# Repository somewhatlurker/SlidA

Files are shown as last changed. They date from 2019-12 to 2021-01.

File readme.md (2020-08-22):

## SlidA

Code based on [Thinithm](https://github.com/somewhatlurker/thinithm) for Diva Arcade FT only sliders.

* Code quality is non-existent
* Only has minimal testing

Hardware is based on ATmega32u4 Arduinos -- (Pro) Micro or Leonardo. (may work on other boards, but I don't know)  
Also requires 3\*MPR121 and (optionally) 32\*WS2812 compatible LEDs (60/meter premade strip should work well).  
Button input is handled through keyboard buttons, but using an separate button encoder is recommended.

Cheap generic MPR121 modules can be used off a <3.3V supply only, so I suggest to pair them with a 3.3V Pro Micro.  
Adafruit MPR121 modules work off 5V and can be used with any compatible board.

Make sure you set the address of your second and third MPR121s:  
1. (For generic modules only) Cut between the ADD pads on the rear side.
2. Solder a jumper from ADD to 3V for the second MPR121, and SDA for the third.

Requires [QuickMpr121](https://github.com/somewhatlurker/QuickMpr121) and FastLED.

Set pins in pins.h or use the defaults (based around Pro Micro):  
| Function | Pin |
| --- | --- |
| MPR121 SDA | SDA |
| MPR121 SCL | SCL |
| MPR121 IRQ | 4 |
| Keyboard W | 5 |
| Keyboard A | 6 |
| Keyboard S | 7 |
| Keyboard D | 8 |
|Keyboard Return | 9 |
|Slider LED Data | 10 |

Slider sensors should be 32 conductive rectangles (eg. copper tape or PCB fills) against the rear side of ~3mm acrylic.  
They are connected sequentially to the MPR121s from left to right.

Buttons connect between the matching pin and ground.

If you have trouble, try limiting the game FPS to <120.

For now, MIT license (subject to change for future versions)

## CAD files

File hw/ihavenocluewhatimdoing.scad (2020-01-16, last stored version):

pcb_width_main = 97;
pcb_width_ledsoffset = 3;
pcb_width_total = pcb_width_main + pcb_width_ledsoffset;
pcb_height_main = 85.7;
pcb_height_leds = 8.1;
pcb_height_total = pcb_height_main + pcb_height_leds;

pcb_hole_dist_x = 6.175;
pcb_hole_dist_y = 3.175;
pcb_hole_size = 3.1;

top_thickness = 2;
key_thickness = 3;
pcb_thickness = 1.6;
space_thickness = 8;
bottom_thickness = 2;
wall_thickness = 2;

wall_height = key_thickness + pcb_thickness + space_thickness;
full_height = top_thickness + wall_height + bottom_thickness;

slider_height = 136;
top_width = 530;
bottom_width = 530;
slider_y_adjust = -9.5;

slider_bevel_x = 44;
slider_bevel_y = 28;

key_separator_width = 3;
key_top_bottom_padding = top_thickness;
key_area_width = pcb_width_main * 4 + key_separator_width;
key_area_height = pcb_height_total - pcb_hole_dist_y*2 - pcb_hole_size - key_top_bottom_padding*2 - .25;

tab_tolerance = 0.05;

hole_resolution = 50;

corner_rounding = 2;


module slider_holes (n = 4)
{
    for (i=[0:n-1])
    {
        translate ([(-pcb_width_main/2) * n + pcb_width_main * i, -pcb_height_total/2, 0])
        {
            translate ([pcb_hole_dist_x, pcb_hole_dist_y, 0])
            {
                circle(pcb_hole_size/2, $fn=hole_resolution);
            }
            translate ([pcb_width_main - pcb_hole_dist_x, pcb_hole_dist_y, 0])
            {
                circle(pcb_hole_size/2, $fn=hole_resolution);
            }
            translate ([pcb_hole_dist_x, pcb_height_total - pcb_hole_dist_y, 0])
            {
                circle(pcb_hole_size/2, $fn=hole_resolution);
            }
            translate ([pcb_width_main - pcb_hole_dist_x, pcb_height_total - pcb_hole_dist_y, 0])
            {
                circle(pcb_hole_size/2, $fn=hole_resolution);
            }
        }
    }
    
    translate ([-key_area_width/2 - pcb_hole_size/2 - .15, 0, 0])
    {
        circle(pcb_hole_size/2, $fn=hole_resolution);
    }
    translate ([key_area_width/2 + pcb_hole_size/2 + .15, 0, 0])
    {
        circle(pcb_hole_size/2, $fn=hole_resolution);
    }
}

module slider_pcbs (n = 4)
{
    corner_rad = 1.27;
    
    color("white", 1.0)
    linear_extrude (height = pcb_thickness)
    difference ()
    {
        for (i=[0:n-1])
        {
            translate ([(-pcb_width_main/2) * n + pcb_width_main * i, -pcb_height_total/2])
            {
                union ()
                {
                    // main body full width (not full height)
                    translate ([0, pcb_height_leds])
                    {
                        square([pcb_width_main, pcb_height_main - corner_rad]);
                    }
                    // main body full height (not full width)
                    translate ([corner_rad, pcb_height_leds])
                    {
                        square([pcb_width_main - corner_rad * 2, pcb_height_main]);
                    }
    
                    // main body corners
                    translate ([corner_rad, pcb_height_total - corner_rad])
                    {
                        circle(r = corner_rad, $fn=hole_resolution);
                    }
                    translate ([pcb_width_main - corner_rad, pcb_height_total - corner_rad])
                    {
                        circle(r = corner_rad, $fn=hole_resolution);
                    }
                    
                    // led section full width (not full height)
                    translate ([pcb_width_ledsoffset, corner_rad])
                    {
                        square([pcb_width_main, pcb_height_leds - corner_rad]);
                    }
                    // led section full height (not full width)
                    translate ([pcb_width_ledsoffset + corner_rad, 0])
                    {
                        square([pcb_width_main - corner_rad * 2, pcb_height_leds]);
                    }
                    
                    // led section corners
                    translate ([pcb_width_ledsoffset + corner_rad, corner_rad])
                    {
                        circle(r = corner_rad, $fn=hole_resolution);
                    }
                    translate ([pcb_width_ledsoffset + pcb_width_main - corner_rad, corner_rad])
                    {
                        circle(r = corner_rad, $fn=hole_resolution);
                    }
                }
            }
        }
        slider_holes(n);
    }
}

module slider_keys (width = key_area_width, height = key_area_height, thickness = key_thickness, top_gap = 0, top_border = key_top_bottom_padding, bottom_border = key_top_bottom_padding + pcb_hole_size + 1.5, top_border_retainer = key_top_bottom_padding)
{
    key_count = 16;
    sep_width = key_separator_width;
    key_width = ((width - (key_count + 1) * key_separator_width) / key_count);
    key_height = height;
    
    
    // keys
    color("blue", 1.0)
    linear_extrude (height = thickness)
    for (i=[0:key_count-1])
    {
        translate ([-width/2 + (sep_width + key_width) * i + sep_width + 0.075, -key_height/2])
        {
            square([key_width - 0.15, key_height - 0.1]);
        }
    }
    
    // separators + frame
    color("green", 1.0)
    linear_extrude (height = thickness)
    difference ()
    {
        union ()
        {
            // separators + frame
            for (i=[0:(key_count)/4 - 1])
            {
                for (j=[0:3])
                {
                    translate ([-width/2 + (sep_width + key_width) * (i*4 + j), -key_height/2])
                    {
                        square([sep_width, key_height]);
                    }
                }
                
                // bottom strip
                translate ([-width/2 + (sep_width + key_width) * i*4, key_height/2])
                {
                    difference ()
                    {
                        square([sep_width*4.5 + key_width*4 - pcb_hole_dist_x + pcb_hole_size/2 + 2, bottom_border]);
                        
                        // cutouts to help control light leakage
                        for (j=[0:3])
                        {
                            translate ([-0.3 + (sep_width + key_width) * j, 0])
                            {
                                square([0.3, bottom_border - 3]);
                            }
                            translate ([sep_width + (sep_width + key_width) * j, 0])
                            {
                                square([0.3, bottom_border - 3]);
                            }
                        }
                    }
                }
            }
            // messy hack to add last separator
            translate ([width/2 - sep_width, -key_height/2])
            {
                square([sep_width, key_height]);
            }
            translate ([width/2 - sep_width/2 - pcb_hole_dist_x + pcb_hole_size/2, key_height/2])
            {
                difference ()
                {
                    square([sep_width/2 + pcb_hole_dist_x - pcb_hole_size/2, bottom_border]);
                    
                    translate ([-0.3 + pcb_hole_dist_x - pcb_hole_size/2 - sep_width/2, 0])
                    {
                        square([0.3, bottom_border - 3]);
                    }
                }
            }
            
            // messy hack for top retainer's retention
            translate ([-width/2, -key_height/2 - top_border_retainer])
            {
                square([sep_width, bottom_border]);
            }
            translate ([width/2 - sep_width, -key_height/2 - top_border_retainer])
            {
                square([sep_width, bottom_border]);
            }
        }
        
        slider_holes(4);
    }
    
    
    // top retainer
    color("red", 1.0)
    linear_extrude (height = thickness)
    {
        translate ([-width/2 + sep_width + 0.1, -key_height/2 - top_border])
        {
            square([(key_width + sep_width) * 4 - 0.1, top_border]);
        }
        translate ([-width/2 + sep_width + (key_width + sep_width) * 4 + 0.1, -key_height/2 - top_border])
        {
            square([(key_width + sep_width) * 4 - 0.1, top_border]);
        }
        translate ([-width/2 + sep_width + (key_width + sep_width) * 8 + 0.1, -key_height/2 - top_border])
        {
            square([(key_width + sep_width) * 4 - 0.1, top_border]);
        }
        translate ([-width/2 + sep_width + (key_width + sep_width) * 12 + 0.1, -key_height/2 - top_border])
        {
            square([(key_width + sep_width) * 4 - sep_width - 0.2, top_border]);
        }
    }
}
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

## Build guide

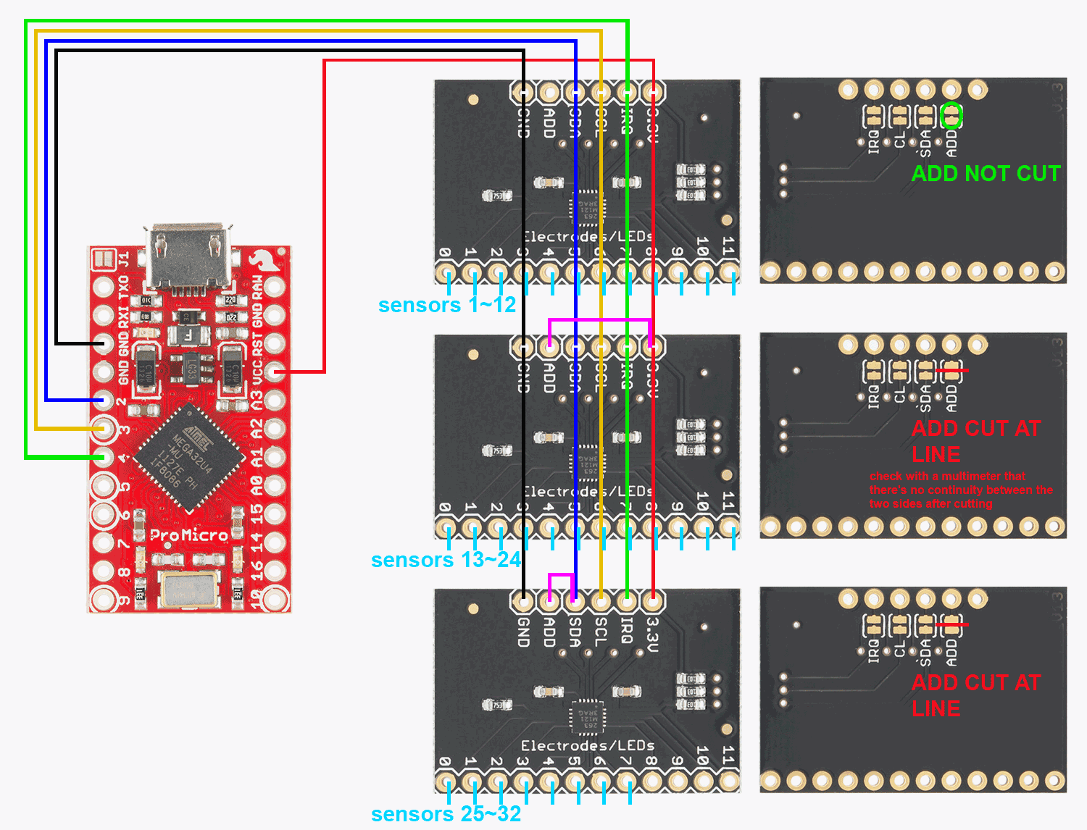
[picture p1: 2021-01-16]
mpr121 wiring.png

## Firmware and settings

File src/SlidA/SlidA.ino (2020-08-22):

#include "segaSlider.h"
#include "sliderdefs.h"
#include "pins.h"
#include <QuickMpr121.h>

#if SLIDER_LEDS
  #include <FastLED.h>
#endif

#if BUTTON_INPUT
  #include <Keyboard.h>
#endif


// disable input scanning and generate fake slider data instead
// (useful for testing protocol without full hardware)
#define FAKE_DATA false

#define FAKE_DATA_TYPE_CHASE 0
#define FAKE_DATA_TYPE_PULSE 1
#define FAKE_DATA_TYPE_TIMERS 2
#define FAKE_DATA_TYPE FAKE_DATA_TYPE_TIMERS

// force enable scanning even with fake data enabled
#define FAKE_DATA_DO_SCANNING true


#if FAKE_DATA && FAKE_DATA_TYPE == FAKE_DATA_TYPE_TIMERS
  #include "debugTimer.h"
  debugTimer loopTimer;
  debugTimer sendTimer;
#endif


#if SLIDER_LEDS
  // slider LED vars
  #define NUM_SLIDER_LEDS 32
  CRGB sliderLeds[NUM_SLIDER_LEDS];
  
  #define RGB_BRIGHTNESS 127
  // 450mA should be unnoticeable up to ~140 brightness, and even then going brighter won't be too bad
  #define RGB_POWER_LIMIT 450
  
  #define MODE_LED_RGB_INDEX NUM_SLIDER_LEDS-1
#endif // SLIDER_LEDS


// status/error LED state
enum errorState : byte {
  ERRORSTATE_NONE = 0, // no error, used for resetting state
  ERRORSTATE_SERIAL_TIMEOUT = 1, // not receiving serial data (timeout)
  ERRORSTATE_PACKET_CHECKSUM = 2, // at least one invalid packet (due to checksum error) was received
  ERRORSTATE_PACKET_OK = 4, // at least one valid packet was received
  ERRORSTATE_PACKET_MAX_REACHED = 8, // number of packets exceeded MAX_PACKETS_PER_LOOP
  ERRORSTATE_SERIAL_SEND_FAILURE = 16, // sendPacket returned false
  ERRORSTATE_MPR_STOPPED = 32, // an mpr121 stopped running
};
errorState operator |(errorState a, errorState b)
{
    return static_cast<errorState>(static_cast<byte>(a) | static_cast<byte>(b));
}
errorState operator |=(errorState &a, errorState b)
{
    return a = (a | b);
}

errorState curError;


// status/error LED pins
#ifdef LED_BUILTIN_RX
  #define STATUS_LED_BASIC_1_PIN LED_BUILTIN_RX // pro micro has no LED_BUILTIN, so use the RX led
  #define STATUS_LED_BASIC_1_USES_RXTX 1
#else
  #define STATUS_LED_BASIC_1_PIN LED_BUILTIN
#endif

#ifdef LED_BUILTIN_TX
  #define STATUS_LED_BASIC_2_PIN LED_BUILTIN_TX // pro micro has no LED_BUILTIN, so use the TX led
  #define STATUS_LED_BASIC_2_USES_RXTX 1
#else
  #define STATUS_LED_BASIC_2_PIN LED_BUILTIN
#endif

#define STATUS_LED_BASIC_1_ERRORS (ERRORSTATE_SERIAL_TIMEOUT | ERRORSTATE_PACKET_CHECKSUM | /*ERRORSTATE_PACKET_MAX_REACHED |*/ ERRORSTATE_SERIAL_SEND_FAILURE | ERRORSTATE_MPR_STOPPED)
#define STATUS_LED_BASIC_2_ERRORS (ERRORSTATE_PACKET_OK)


// slider serial protocol implementation
segaSlider sliderProtocol = segaSlider(&Serial);


// slider protocol packets for reuse
byte sliderBuf[32];
sliderPacket scanPacket = { SLIDER_SCAN_REPORT, sliderBuf, 32, true };

byte emptyBytes[0];
sliderPacket emptyPacket = { (sliderCommand)0, emptyBytes, 0, true }; // command will be replaced as necessary

boardInfo boardInfoData;
sliderPacket boardinfoPacket = { SLIDER_BOARDINFO, (byte*)&boardInfoData, sizeof(boardInfo), true };


// mpr121s
#define NUM_MPRS 3
mpr121 mprs[NUM_MPRS];


// loop timing/processing stuff

// sleep for x microseconds after running the main loop
#define LOOP_SLEEP_US 333

// time to wait after losing serial connection before disabling scan and LEDs
#define SERIAL_TIMEOUT_MS 10000

// maximum number of received serial packets to process in one loop
#define MAX_PACKETS_PER_LOOP 1


void setup() {
  // set pin modes for stuff that's handled in the main sketch file
  pinMode(STATUS_LED_BASIC_1_PIN, OUTPUT);
  pinMode(STATUS_LED_BASIC_2_PIN, OUTPUT);
  pinMode(PIN_SLIDER_IRQ, INPUT);

  #if BUTTON_INPUT
    for (kbInput &kbi : kbButtons) {
      pinMode(kbi.pin, INPUT_PULLUP);
    }
  #endif // BUTTON_INPUT

  // turn on led during setup
  // not gonna bother shifting this to the status lights
  digitalWrite(LED_BUILTIN, LOW);


  #if !FAKE_DATA || FAKE_DATA_DO_SCANNING
    for (mpr121 &mpr : mprs) {
      mpr.begin();
      mpr.ESI = MPR_ESI_1; // get 4ms response time (4 samples * 1ms rate)
      mpr.autoConfigUSL = 256L * (3200 - 700) / 3200; // set autoconfig for 3.2V
    }
  #endif // !FAKE_DATA || FAKE_DATA_DO_SCANNING


  #if SLIDER_LEDS
    // 5V is LED voltage, not arduino voltage
    FastLED.setMaxPowerInVoltsAndMilliamps(5, RGB_POWER_LIMIT); 
    
    // originally I used SK6812, but they should be WS2812(B) compatible
    FastLED.addLeds<WS2812B, PIN_SLIDER_LED, GRB>(sliderLeds, NUM_SLIDER_LEDS);
  #endif // SLIDER_LEDS


  Serial.setTimeout(0);
  Serial.begin(115200);
  while(!Serial) {} // wait for serial to be ready on USB boards
}


bool scanOn = false;

// enable or disable slider and button scanning
void setScanning(bool on_off) {
  if (on_off && !scanOn) {
    scanOn = true;
    #if !FAKE_DATA || FAKE_DATA_DO_SCANNING
      for (mpr121 &mpr : mprs) {
        mpr.start(12);
      }
      #if BUTTON_INPUT
        Keyboard.begin();
      #endif
    #endif // !FAKE_DATA || FAKE_DATA_DO_SCANNING
  }
  else if (!on_off && scanOn) {
    scanOn = false;
    #if !FAKE_DATA || FAKE_DATA_DO_SCANNING
      for (mpr121 &mpr : mprs) {
        mpr.stop();
      }
      #if BUTTON_INPUT
        Keyboard.releaseAll();
        Keyboard.end();
      #endif
    #endif // !FAKE_DATA || FAKE_DATA_DO_SCANNING
  }
}

// perform a slider scan and send it to sliderProtocol
void doSliderScan() {
  // clear the output buffer
  memset(sliderBuf, 0, sizeof(sliderBuf));
  
  #if FAKE_DATA
    #if FAKE_DATA_TYPE == FAKE_DATA_TYPE_CHASE
      sliderBuf[(millis()/30) % 32] = 0xC0;
    #elif FAKE_DATA_TYPE == FAKE_DATA_TYPE_PULSE
      sliderBuf[0] = (millis() % 1000) < 150 ? 0xC0 : 0x00;
    #elif FAKE_DATA_TYPE == FAKE_DATA_TYPE_TIMERS
      sendTimer.log();
      
      sliderBuf[0] = loopTimer.getMinMicros() / 1000;
      sliderBuf[1] = loopTimer.getAverageMicros() / 1000;
      sliderBuf[2] = loopTimer.getMaxMicros() / 1000;
      
      sliderBuf[4] = sendTimer.getMinMicros() / 1000;
      sliderBuf[5] = sendTimer.getAverageMicros() / 1000;
      sliderBuf[6] = sendTimer.getMaxMicros() / 1000;

      static unsigned long lastResetMillis;
      if (millis() - lastResetMillis > 3000) {
        sendTimer.reset();
        loopTimer.reset();
        lastResetMillis = millis();
      }
    #endif
  #endif // FAKE_DATA
  
  #if !FAKE_DATA || FAKE_DATA_DO_SCANNING
    static const byte numInputTouches = 12 * NUM_MPRS;
    static bool allTouches[numInputTouches];
  
    // read all mpr touches into allTouches
    for (byte i = 0; i < NUM_MPRS; i++) {
      mpr121 &mpr = mprs[i];

      // error condition, should hopefully never be triggered
      if (!mpr.checkRunning()) {
        curError |= ERRORSTATE_MPR_STOPPED;
        setScanning(false);
        return;
      }
      
      #if MPR121_USE_BITFIELDS
        short touches = mpr.readTouchState();
        for (byte j = 0; j < 12; j++) {
          allTouches[12*i + j] = bitRead(touches, j);
        }
      #else // MPR121_USE_BITFIELDS
        bool* touches = mpr.readTouchState();
        memcpy(&allTouches[12*i], touches, sizeof(bool[12]));
      #endif // MPR121_USE_BITFIELDS
    }

    #if !FAKE_DATA
      // apply touch data to output buffer
      for (byte i = 0; i < divaSlider.keyCount && i < sizeof(sliderBuf); i++) { // for all keys, with bounds limited
        byte inputPos = divaSlider.keyMap[i];
  
        if (inputPos < numInputTouches && allTouches[inputPos]) { // check the result to read is in-range
          sliderBuf[i] |=  0xC0; // note this uses bitwise or to stack nicely
        }
      }
    #endif // !FAKE_DATA
  #endif // !FAKE_DATA || FAKE_DATA_DO_SCANNING
  
  if (!sliderProtocol.sendPacket(scanPacket))
    curError |= ERRORSTATE_SERIAL_SEND_FAILURE;
}

#if BUTTON_INPUT
  // perform a button scan and send it to Keyboard
  void doButtonScan() {
    #if !FAKE_DATA || FAKE_DATA_DO_SCANNING
      for (kbInput &kbi : kbButtons) {
        bool state = digitalRead(kbi.pin);
        #if !FAKE_DATA
          if (state != kbi.lastState) {
            if (state == LOW) // LOW is pressed
              Keyboard.press(kbi.key);
            else
              Keyboard.release(kbi.key);

            kbi.lastState = state;
          }
        #endif // !FAKE_DATE
      }
    #endif // !FAKE_DATA || FAKE_DATA_DO_SCANNING
  }
#endif


// timing vars used in main loop
int sleepTime = LOOP_SLEEP_US;
unsigned long lastSliderSendMillis;
unsigned long lastSerialRecvMillis = -SERIAL_TIMEOUT_MS;
unsigned long loopCount = 0;

#if SLIDER_LEDS
  bool ledUpdate = false;
#endif // SLIDER_LEDS

void loop() {
  // clear errors (they'll be reset if necessary)
  curError = ERRORSTATE_NONE;

  // check for new slider data
  byte pktCount = 0;
  while (pktCount < MAX_PACKETS_PER_LOOP) {
    sliderPacket pkt = sliderProtocol.getPacket();

    // if there was no data or the buffer was incomplete, `Command` will equal `(sliderCommand)0`
    // there's no point in looping here if there's no data or not enough data
    if (pkt.Command == (sliderCommand)0) {
      break;
    }

    // increment these when there's any packets, valid or not
    lastSerialRecvMillis = millis();
    pktCount++;

    // check if the packet checksum was valid, and skip handling the packet if it wasn't
    if (pkt.IsValid) {
      curError |= ERRORSTATE_PACKET_OK;
    }
    else {
      curError |= ERRORSTATE_PACKET_CHECKSUM;
      continue;
    }

    switch(pkt.Command) {
      case SLIDER_BOARDINFO:
        memcpy(boardInfoData.model, divaSlider.model, sizeof(boardInfo::model));
        memcpy(boardInfoData.chipNumber, divaSlider.chipNumber, sizeof(boardInfo::chipNumber));
        if (!sliderProtocol.sendPacket(boardinfoPacket))
          curError |= ERRORSTATE_SERIAL_SEND_FAILURE;
        break;

      case SLIDER_SCAN_REPORT:
        // there's no way this will give accurate results,
        // but at least it's implemented on a protocol level now
        if (!scanOn) {
          setScanning(true);
          delay(10);
          doSliderScan();
          setScanning(false);
        }
        break; // doSliderScan() sends the response
        
      case SLIDER_SCAN_ON:
        sliderProtocol.sendPacket(scanPacket);
        setScanning(true);
        break; // no response needed
        
      case SLIDER_SCAN_OFF:
        setScanning(false);
        emptyPacket.Command = SLIDER_SCAN_OFF;
        if (!sliderProtocol.sendPacket(emptyPacket))
          curError |= ERRORSTATE_SERIAL_SEND_FAILURE;
        break;
        
      case SLIDER_LED:
        #if SLIDER_LEDS
          if (pkt.DataLength > 0) {
            FastLED.setBrightness((pkt.Data[0] & 0x3f) * RGB_BRIGHTNESS / 0x3f); // this seems to max out at 0x3f (63), use that for division
  
            byte maxPacketLeds = (pkt.DataLength - 1) / 3; // subtract 1 because of brightness byte
            
            for (byte i = 0; i < divaSlider.ledCount; i++) {
              byte outputLed = divaSlider.ledMap[i];
  
              if (outputLed < NUM_SLIDER_LEDS) { // make sure there's no out of bounds writes
                if (i < maxPacketLeds) {
                  if (outputLed % 2 == 0) {
                    sliderLeds[outputLed].b = pkt.Data[i*3 + 1]; // start with + 1 because of brightness byte
                    sliderLeds[outputLed].r = pkt.Data[i*3 + 2];
                    sliderLeds[outputLed].g = pkt.Data[i*3 + 3];
                  }
                  else {
                    // dim values for separators
                    sliderLeds[outputLed].b = pkt.Data[i*3 + 1] / 2; // start with + 1 because of brightness byte
                    sliderLeds[outputLed].r = pkt.Data[i*3 + 2] / 2;
                    sliderLeds[outputLed].g = pkt.Data[i*3 + 3] / 2;
                  }
                }
                else {
                  sliderLeds[outputLed] = CRGB::Black;
                }
              }
            }
            ledUpdate = true;
          }
        #endif // SLIDER_LEDS
        break; // no response needed
        
      default:
        emptyPacket.Command = pkt.Command; // just blindly acknowledge unknown commands
        if (!sliderProtocol.sendPacket(emptyPacket))
          curError |= ERRORSTATE_SERIAL_SEND_FAILURE;
        break;
    }
  }
  if (pktCount == MAX_PACKETS_PER_LOOP)
    curError |= ERRORSTATE_PACKET_MAX_REACHED;

  // disable scan and set error if serial is dead
  if ((millis() - lastSerialRecvMillis) > SERIAL_TIMEOUT_MS) {
    if (scanOn) {
      setScanning(false);
    }
    curError |= ERRORSTATE_SERIAL_TIMEOUT;


    #if SLIDER_LEDS
      // set mode colour for 5s (this should trigger at boot)
      // also use this to black out slider
      if ((millis() - lastSerialRecvMillis) < SERIAL_TIMEOUT_MS + 5000) {
        FastLED.setBrightness(RGB_BRIGHTNESS);
  
        for (byte i = 0; i < NUM_SLIDER_LEDS; i++) {
          sliderLeds[i] = CRGB::Black;
        }
        
        sliderLeds[MODE_LED_RGB_INDEX] = CRGB::Teal;
  
        ledUpdate = true;
      }
      else {
        if (sliderLeds[MODE_LED_RGB_INDEX] != (CRGB)CRGB::Black) {
          sliderLeds[MODE_LED_RGB_INDEX] = CRGB::Black;
          ledUpdate = true;
        }
      }
    #endif // SLIDER_LEDS
  }

  #if SLIDER_LEDS
    // now update LEDs once per loop
    // done before scanning to reduce delay from receiving to showing
    if (ledUpdate) {
      FastLED.show();
      ledUpdate = false;
    }
  #endif // SLIDER_LEDS

  // if slider scanning is on, update inputs (as appropriate)
  if (scanOn) {
    
    // if slider touch state has changed (interrupt was triggered), send data (currently disabled)
    // also send data anyway if slider touch state hasn't changed recently
    if ( /*(digitalRead(PIN_SLIDER_IRQ) == LOW) ||*/ ((millis() - lastSliderSendMillis) > 10) ) {
      lastSliderSendMillis = millis();
      doSliderScan();
    }

    #if BUTTON_INPUT
      doButtonScan();
    #endif
  }


  // set status leds
  if (STATUS_LED_BASIC_1_ERRORS & curError) {
    #ifdef STATUS_LED_BASIC_1_USES_RXTX
      pinMode(STATUS_LED_BASIC_1_PIN, OUTPUT); // set as OUTPUT to re-enable normal operation
    #endif
    digitalWrite(STATUS_LED_BASIC_1_PIN, LOW);
  }
  else {
    #ifdef STATUS_LED_BASIC_1_USES_RXTX
      pinMode(STATUS_LED_BASIC_1_PIN, INPUT); // set as INPUT to disable normal operation
    #endif
    digitalWrite(STATUS_LED_BASIC_1_PIN, HIGH);
  }

  if (STATUS_LED_BASIC_2_ERRORS & curError) {
    #ifdef STATUS_LED_BASIC_2_USES_RXTX
      pinMode(STATUS_LED_BASIC_2_PIN, OUTPUT); // set as OUTPUT to re-enable normal operation
    #endif
    digitalWrite(STATUS_LED_BASIC_2_PIN, LOW);
  }
  else {
    #ifdef STATUS_LED_BASIC_2_USES_RXTX
      pinMode(STATUS_LED_BASIC_2_PIN, INPUT); // set as INPUT to disable normal operation
    #endif
    digitalWrite(STATUS_LED_BASIC_2_PIN, HIGH);
  }

  loopCount++;

  #if FAKE_DATA && FAKE_DATA_TYPE == FAKE_DATA_TYPE_TIMERS
    loopTimer.log();
  #endif

  delayMicroseconds(sleepTime);
}

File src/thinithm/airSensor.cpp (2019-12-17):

#include "airSensor.h"

// set which LED should be enabled (-1 for off)
void airSensor::changeLed(byte led) {
  switch (led) {
    case 0:
      pinMode(pins.leds[0], OUTPUT);
      pinMode(pins.leds[1], OUTPUT);
      pinMode(pins.leds[2], INPUT);
      
      digitalWrite(pins.leds[0], HIGH);
      digitalWrite(pins.leds[1], LOW);
      digitalWrite(pins.leds[2], LOW);
      
      break;
      
    case 1:
      pinMode(pins.leds[0], OUTPUT);
      pinMode(pins.leds[1], OUTPUT);
      pinMode(pins.leds[2], INPUT);
      
      digitalWrite(pins.leds[0], LOW);
      digitalWrite(pins.leds[1], HIGH);
      digitalWrite(pins.leds[2], LOW);
      
      break;
      
    case 2:
      pinMode(pins.leds[0], INPUT);
      pinMode(pins.leds[1], OUTPUT);
      pinMode(pins.leds[2], OUTPUT);
      
      digitalWrite(pins.leds[0], LOW);
      digitalWrite(pins.leds[1], HIGH);
      digitalWrite(pins.leds[2], LOW);
      
      break;
      
    case 3:
      pinMode(pins.leds[0], INPUT);
      pinMode(pins.leds[1], OUTPUT);
      pinMode(pins.leds[2], OUTPUT);
      
      digitalWrite(pins.leds[0], LOW);
      digitalWrite(pins.leds[1], LOW);
      digitalWrite(pins.leds[2], HIGH);
      
      break;
      
    case 4:
      pinMode(pins.leds[0], OUTPUT);
      pinMode(pins.leds[1], INPUT);
      pinMode(pins.leds[2], OUTPUT);
      
      digitalWrite(pins.leds[0], HIGH);
      digitalWrite(pins.leds[1], LOW);
      digitalWrite(pins.leds[2], LOW);
      
      break;
      
    case 5:
      pinMode(pins.leds[0], OUTPUT);
      pinMode(pins.leds[1], INPUT);
      pinMode(pins.leds[2], OUTPUT);
      
      digitalWrite(pins.leds[0], LOW);
      digitalWrite(pins.leds[1], LOW);
      digitalWrite(pins.leds[2], HIGH);
      
      break;
      
    default:
      pinMode(pins.leds[0], OUTPUT);
      pinMode(pins.leds[1], OUTPUT);
      pinMode(pins.leds[2], OUTPUT);
      
      digitalWrite(pins.leds[0], LOW);
      digitalWrite(pins.leds[1], LOW);
      digitalWrite(pins.leds[2], LOW);
      
      break;
  }
}

// read a raw sensor pin
int airSensor::readSensor(byte sensor) {
  if (sensor < 0 || sensor > 5)
    return 0;

  #if AIR_USE_ANALOG
    return analogRead(pins.sensors[sensor]);
  #else
    return digitalRead(pins.sensors[sensor]);
  #endif
}

// read a raw sensor level value (with LED switched)
int airSensor::readLevelVal(byte level) {
  changeLed(level);
  delayMicroseconds(AIR_HOLD_US); // allow some time for switching to occur
  int val = readSensor(level);
  killLeds();
  return val;
}

#if AIR_USE_ANALOG
// update a baseline
void airSensor::updateBaseline(byte level, int val) {
  // use some static floats to save on floating point operations
  static float multiplier = 1 / (float)AIR_BASELINE_AVERAGING;
  static float one_minus_multiplier = 1 - multiplier;
  
  sensorBaselines[level] = val * multiplier + sensorBaselines[level] * one_minus_multiplier;
}

// update a threshold
void airSensor::updateThreshold(byte level, int val) {
  // use some static floats to save on floating point operations
  static float multiplier = 1 / (float)AIR_THRESHOLD_AVERAGING;
  static float one_minus_multiplier = 1 - multiplier;
  
  sensorThresholds[level] = val * multiplier + sensorThresholds[level] * one_minus_multiplier;
}

// update an averaged level value
void airSensor::updateAveragedVal(byte level, int val) {
  // use some static floats to save on floating point operations
  static float multiplier = 1 / (float)AIR_VALUE_AVERAGING;
  static float one_minus_multiplier = 1 - multiplier;
  
  averagedVals[level] = val * multiplier + averagedVals[level] * one_minus_multiplier;
}
#endif // AIR_USE_ANALOG

// create a sensor
airSensor::airSensor(airSensorPins pinstruct) {
  pins = pinstruct;
  
  pinMode(pins.sensors[0], INPUT);
  pinMode(pins.sensors[1], INPUT);
  pinMode(pins.sensors[2], INPUT);
  pinMode(pins.sensors[3], INPUT);
  pinMode(pins.sensors[4], INPUT);
  pinMode(pins.sensors[5], INPUT);
}

// read whether an air level has been blocked
bool airSensor::checkLevel(byte level) {
  if (level < 0 || level > 5)
    return false;

  #if AIR_USE_ANALOG
    if (!isCalibrated)
      calibrate();
  
    updateAveragedVal(level, readLevelVal(level));
    int delta = sensorBaselines[level] - averagedVals[level];
    
    if (delta > sensorThresholds[level]) {
      updateThreshold(level, delta / AIR_THRESHOLD_DIVISOR);
      return true;
    }
    else {
      updateBaseline(level, averagedVals[level]);
      return false;
    }
  #else // AIR_USE_ANALOG
    return readLevelVal(level) == LOW ? true : false;
  #endif // AIR_USE_ANALOG
}

// read whether all air levels have been blocked (returns pointer to an array of bools)
bool* airSensor::checkAll() {
  static bool buf[6];
  for (int i = 0; i < 6; i++) {
    buf[i] = checkLevel(i);
  }
  return buf;
}

#if AIR_USE_ANALOG
// (re-)calibrate the sensors
// use offset to continue calibrating after already calibrating a number of samples
void airSensor::calibrate(byte samples, byte offset) {
  if (offset == 0) {
    // reset averages, baselines, and thresholds
    // actually completely unnecessary
    for (int i = 0; i < 6; i++) {
      averagedVals[i] = 800;
      sensorBaselines[i] = 800;
      sensorThresholds[i] = 100;
    }
  }
  
  // find baseline values for sensor on and save averaged vals
  for (float spl = 1; spl <= samples; spl++) {
    for (int i = 0; i < 6; i++) {
      int val = readLevelVal(i); // readLevelVal uses LEDs

      float multiplier = 1 / (spl + offset);
      float one_minus_multiplier = 1 - multiplier;
      
      // use custom averages update that takes into account number of samples taken
      averagedVals[i] = val * multiplier + averagedVals[i] * one_minus_multiplier;
      
      // use custom baseline update that takes into account number of samples taken
      sensorBaselines[i] = val * multiplier + sensorBaselines[i] * one_minus_multiplier;
    }
  }
  
  // find threshold values for sensor off
  for (float spl = 1; spl <= samples; spl++) {
    for (int i = 0; i < 6; i++) {
      int val = readSensor(i); // readSensor doesn't use LEDs
      int delta = sensorBaselines[i] - val;

      float multiplier = 1 / (spl + offset);
      float one_minus_multiplier = 1 - multiplier;
      
      // use custom threshold update that takes into account number of samples taken
      sensorThresholds[i] = (delta / AIR_THRESHOLD_DIVISOR) * multiplier + sensorThresholds[i] * one_minus_multiplier;
    }
    delayMicroseconds(AIR_HOLD_US); // should ensure there's some delay...
  }

  isCalibrated = true;
}
#endif // AIR_USE_ANALOG

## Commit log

2019-11-23 fix dir structure, add mpr121example
    [protocol.cpp, thinithm.ino]
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2019-11-28 led bug fixes
2019-12-11 add a little error handling stuff
    [thinithm.ino]
2019-12-11 improve basic error LED code
    [thinithm.ino]
2019-12-11 support two basic error lights
    [thinithm.ino]
2019-12-12 fix slider protocol error detection (by making it possible to tell when invalid packets are just because of the buffer ending)
    [thinithm.ino]
2019-12-12 fix broken slider protocol error handling check
    [thinithm.ino]
2019-12-13 add comments to errorState enum, check scanOn before bothering to disable it in serial rx timeout
    [thinithm.ino]
2019-12-13 reduce memory consumption by segaSlider, fix crashes in mpr121 constructor
    [thinithm.ino]
2019-12-15 fix mpr121 USL calc for <32 bit processors
    [thinithm.ino]
2019-12-16 working on air sensor, code probably doesn't work yet but whatever
    [airSensor.cpp, thinithm.ino]
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2019-12-16 make baseline calibration same as averaged values calibration
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2019-12-17 airSensor: allow "continuing" calibration to add more samples
2019-12-18 airTower: track failed sensors and ignore their results
2019-12-20 add an scad slider model I've been playing with (the file name should indicate the quality well lol)
    [ihavenocluewhatimdoing.scad]
2019-12-20 fix openscad z-fighting issues, add basic walls and bottom
    [ihavenocluewhatimdoing.scad]
2019-12-20 cad: increase circle/cylinder resolution, tweak tolerances around screws
    [ihavenocluewhatimdoing.scad]
2019-12-20 use more 2d scad operations
    [ihavenocluewhatimdoing.scad]
2019-12-20 cad: change some parameters, make bottom panel wider than top
    [ihavenocluewhatimdoing.scad]
2019-12-20 adjust slider shape and add hole for micro usb connector
    [ihavenocluewhatimdoing.scad]
2019-12-20 very slightly adjust spacing in cad
    [ihavenocluewhatimdoing.scad]
2019-12-20 scad: shrunk side margins of slider
    [ihavenocluewhatimdoing.scad]
2019-12-20 more tabs on walls
    [ihavenocluewhatimdoing.scad]
2019-12-20 add extra screw holes
    [ihavenocluewhatimdoing.scad]
2019-12-20 make wall tab corners look nicer
    [ihavenocluewhatimdoing.scad]
2019-12-20 readjust tab count on walls
    [ihavenocluewhatimdoing.scad]
2019-12-20 cad: add hole for switch
    [ihavenocluewhatimdoing.scad]
2019-12-21 cad: add hole for reset button
    [ihavenocluewhatimdoing.scad]
2019-12-21 add slider mode indicator on boot/serial loss
    [ihavenocluewhatimdoing.scad]
2019-12-21 add customizer parameters for tons of stuff
    [ihavenocluewhatimdoing.scad]
2019-12-21 more scad parameterization
    [ihavenocluewhatimdoing.scad]
2019-12-21 scad: create 2d slider projection
    [ihavenocluewhatimdoing.scad]
2019-12-21 add tab tolerances to cad design
    [ihavenocluewhatimdoing.scad]
2019-12-22 scad: configurable hole resolution, reduce amount of geometry within minkowski blocks
    [ihavenocluewhatimdoing.scad]
2019-12-22 cad: make 2d layout automatic, add a short help file with some considerations
    [ihavenocluewhatimdoing.scad]
2019-12-22 add rubber feet to 3d cad render (because why not? lol)
    [ihavenocluewhatimdoing.scad]
2019-12-22 adjust some 2d slider elements to account for laser kerf
    [ihavenocluewhatimdoing.scad]
2019-12-22 better kerf adjustment
    [ihavenocluewhatimdoing.scad]
2019-12-22 better 2d design export process
    [ihavenocluewhatimdoing.scad]
2019-12-22 better parameters for slider_keys in slider_2d_top
    [ihavenocluewhatimdoing.scad]
2019-12-22 cad: add extra screws to retain slider top/bottom padding, remove two extra screws in covers to match quantities I ordered
    [ihavenocluewhatimdoing.scad]
2019-12-22 adjust slider key top/bottom sections to fit better
    [ihavenocluewhatimdoing.scad]
2019-12-23 more efficient 2d slider wall layout
    [ihavenocluewhatimdoing.scad]
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2019-12-26 wait for serial connection on USB boards during setup
2019-12-26 replace commented out sketch code with a define to toggle it (FAKE_DATA)
    [thinithm.ino]
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2019-12-29 fix printout of mpr121example analog mode
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2019-12-30 scad: change a couple of hole sizes
    [ihavenocluewhatimdoing.scad]
2019-12-31 fix chuni mapping, fix initial value of lastSerialRecvMillis, increase keep awake interval to 500ms, change some comments
    [thinithm.ino]
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2020-01-01 mpr121: fix OOR reads, change use of buffers slightly (doesn't affect users), add untested option to use bitfields for touch state and OOR reads instead of bools (can be enabled by a define, saves 13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
    [thinithm.ino]
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2020-01-01 mpr121: fix description of pin 9 pwm bug
2020-01-02 scad: new key separator design
    [ihavenocluewhatimdoing.scad]
2020-01-02 scad: further adjust keys to remove some screws
    [ihavenocluewhatimdoing.scad]
2020-01-05 playing around with an air arm shape
    [ihavenocluewhatimdoing.scad]
2020-01-06 scad: more progress on air sensor
    [ihavenocluewhatimdoing.scad]
2020-01-06 scad: more air tower work, corner rounding
    [ihavenocluewhatimdoing.scad]
2020-01-06 handle bad serial data better, don't count truncated buffers towards ERRORSTATE_PACKET_MAX_REACHED
    [thinithm.ino]
2020-01-07 perform an LED update every loop, and adjust LOOP_SLEEP_US to be reduced by the amount of time that should take (should make performance a little more consistent)
2020-01-07 now only call FastLED.show() if led data was updated, reinstate end of loop delay at a reduced duration of 333 us
2020-01-08 simplify segaSlider usage, add way to check for tx errors, only process one packet per loop
    [thinithm.ino]
2020-01-10 scad: more experimenting with air arm
    [ihavenocluewhatimdoing.scad]
2020-01-10 scad: some more details of air arms, improve performance by avoiding minkowski (emulated using offset and adjusting extrusions)
    [ihavenocluewhatimdoing.scad]
2020-01-10 scad: more supports for air arm inner layers
    [ihavenocluewhatimdoing.scad]
2020-01-10 scad: fix air arm wall cutouts
    [ihavenocluewhatimdoing.scad]
2020-01-10 redesign air tower top tabs to hopefully fit more snug
    [ihavenocluewhatimdoing.scad]
2020-01-10 scad: maybe final adjustment to air top tabs and positioning, add visualisation of LEDs in 3D
    [ihavenocluewhatimdoing.scad]
2020-01-10 rounded caps on LEDs
    [ihavenocluewhatimdoing.scad]
2020-01-10 scad: make corrections to air tower base tabs and screws
    [ihavenocluewhatimdoing.scad]
2020-01-10 scad: adjust air arm screws for more clearance inside
    [ihavenocluewhatimdoing.scad]
2020-01-10 scad: increase air inner layer wall thicknesses
    [ihavenocluewhatimdoing.scad]
2020-01-10 scad: rearrange air tower holes
    [ihavenocluewhatimdoing.scad]
2020-01-10 scad: split key retainer up more
    [ihavenocluewhatimdoing.scad]
2020-01-10 another round of air tower tweaking
    [ihavenocluewhatimdoing.scad]
2020-01-11 scad: yet another air tower overhaul
    [ihavenocluewhatimdoing.scad]
2020-01-11 increase top layer to 2mm
    [ihavenocluewhatimdoing.scad]
2020-01-11 scad: make full 2d air layout, include additional key retainers
    [ihavenocluewhatimdoing.scad]
2020-01-11 fix fit of air arm
    [ihavenocluewhatimdoing.scad]
2020-01-11 make slider wider
    [ihavenocluewhatimdoing.scad]
2020-01-11 scad: fix air arm tab sizing, use hex holes for air arm inner layers
    [ihavenocluewhatimdoing.scad]
2020-01-11 scad: reduce air arm inner hole size
    [ihavenocluewhatimdoing.scad]
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2020-01-11 scad: adjust full 2d preview spacing, swap air arm sides in 3d preview so reset button and mode switch are visible
    [ihavenocluewhatimdoing.scad]
2020-01-11 fix compiler warnings, and fix a couple of mpr121 bugs (release thresholds and ACE flag)
    [thinithm.ino]
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2020-01-13 mpr121: rename `startMPR` and `stopMPR` to `start` and `stop`, add optional `begin` function as an alternative to using Wire directly in sketch, add `checkRunning` function
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2020-01-13 mpr121: end Wire lib before begin, remove call to deprected stopMPR in start
2020-01-13 mpr121: started writing better comment docs, fixed GPIO pin range checks, added pin names
2020-01-14 switch mpr121 code to QuickMpr121 library (same code moved into a library)
2020-01-16 scad: increase width to 530, move air arm tab location to line up with wall tabs, add air arm cable holes
    [ihavenocluewhatimdoing.scad]
2020-08-22 fork to SlidA
    [ihavenocluewhatimdoing.scad]
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
